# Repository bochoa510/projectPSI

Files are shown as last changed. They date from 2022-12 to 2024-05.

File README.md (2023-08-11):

# projectPSI : Automatic Tire Inflator prototype 

# Index

* CAD
  - housing design using OnShapeCAD
    
*  Code
   - source code used to program microcontroller
 
* Parts
    - detailed list of components used and links 
    
* Previous versions
  - previous versions, keeping for project history
    
* Resources
   - parts resources  
     
* Schematics
   - KiCAD schematic files and board design

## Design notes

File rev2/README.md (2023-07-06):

# to do:

update maincontrol to correctly measure and display PSI

# fix layout design problems:

   I2C pins
   
  pull down resistors for transistors

# goal is to have self contained pcb:

  5v relay moodule w/ isolation
  
  16bit adc module 

# I would like to include surface mount components:

  capacitors
  
  resistors
  
  diodes
  
  atmega328p (maybe)

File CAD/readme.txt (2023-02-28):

Created using OnShape 3D CAD and 3D printed test parts using Makerbot Replicator 5th Gen 

Link to part document
https://cad.onshape.com/documents/6e8889402c3ba4208828449b/w/36755877a1c921f2bab17a01/e/a95ed9e188de5fe185a65eca

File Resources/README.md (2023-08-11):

# Supporting files and resources used to create the PCB and Code 

# Index
* ADS1115
  - adc converter
* 5V Relay Module
  - Relay module with optocoupler isolation

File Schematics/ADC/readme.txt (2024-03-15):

Analog to digital converter schematic and pcb design

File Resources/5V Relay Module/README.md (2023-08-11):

deciding on schematic options

no optocoupler isolation + active high trigger 

(https://components101.com/switches/5v-single-channel-relay-module-pinout-features-applications-working-datasheet)


with optocoupler isolation + active high/low trigger



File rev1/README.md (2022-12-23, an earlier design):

maincontrol.ino contains atmega328p code 

pPSI.zip contains kicad layout files

improvements for rev2

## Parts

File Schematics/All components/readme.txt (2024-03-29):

all parts (excluding 328p section) combined to a single pcb to test complete functionality

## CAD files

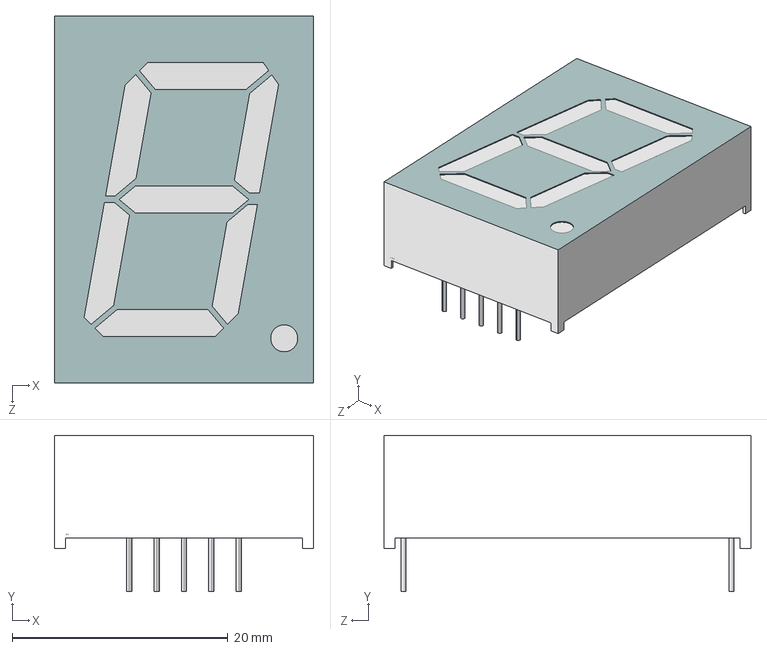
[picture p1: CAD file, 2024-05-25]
CAD/7seg.step
24.0 x 14.5 x 34.0 mm

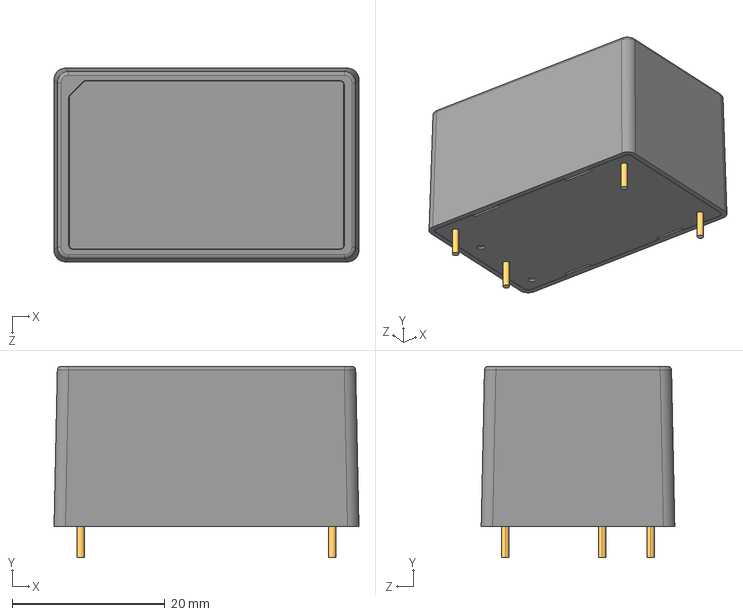
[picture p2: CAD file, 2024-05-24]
Schematics/KiCAD Parts Library/zipfiles/PSK-10D-5/PSK-10D-5.step
40.0 x 25.1 x 25.4 mm

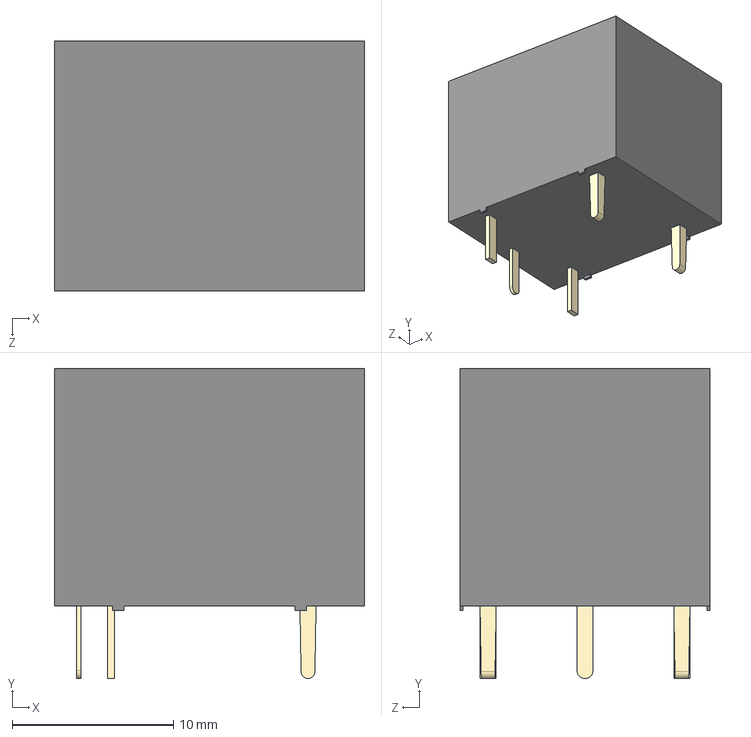
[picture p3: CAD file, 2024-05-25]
CAD/relay.step
19.2 x 19.2 x 15.5 mm

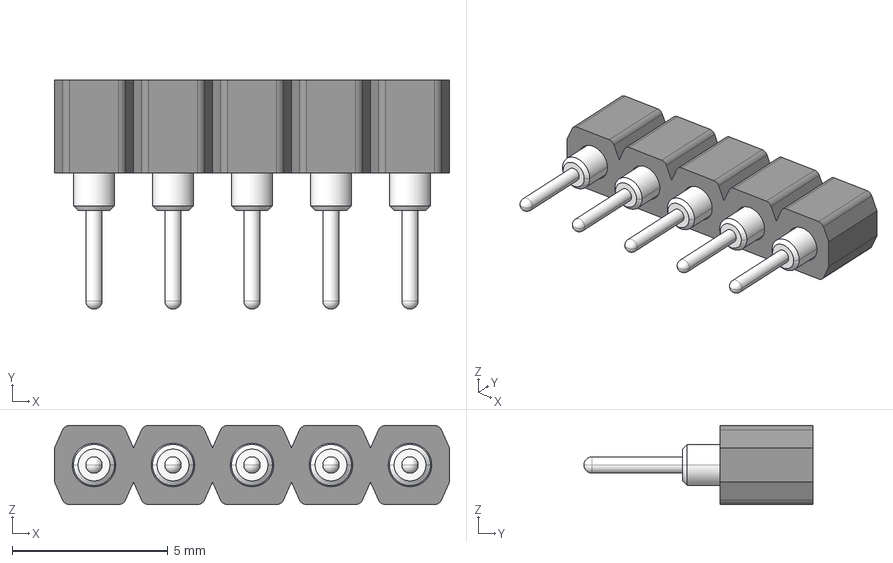
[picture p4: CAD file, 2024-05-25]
CAD/5 pin female header.stp
12.7 x 7.37 x 2.54 mm
D01-997-MOULDING
D01-997-SOCKETBODY x 5
Y3199 x 5

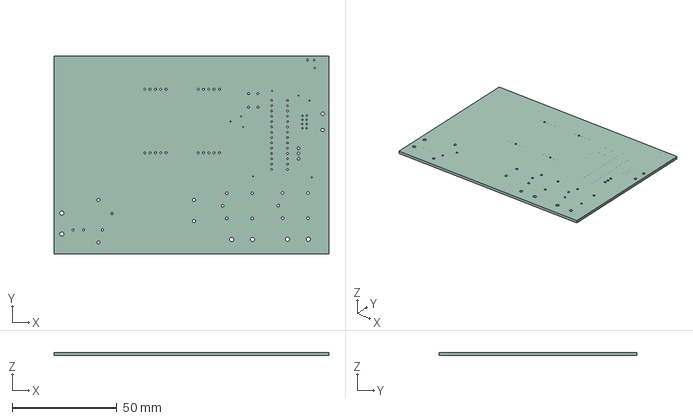
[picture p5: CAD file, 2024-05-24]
CAD/all_components.step
131.5 x 94.8 x 1.60 mm

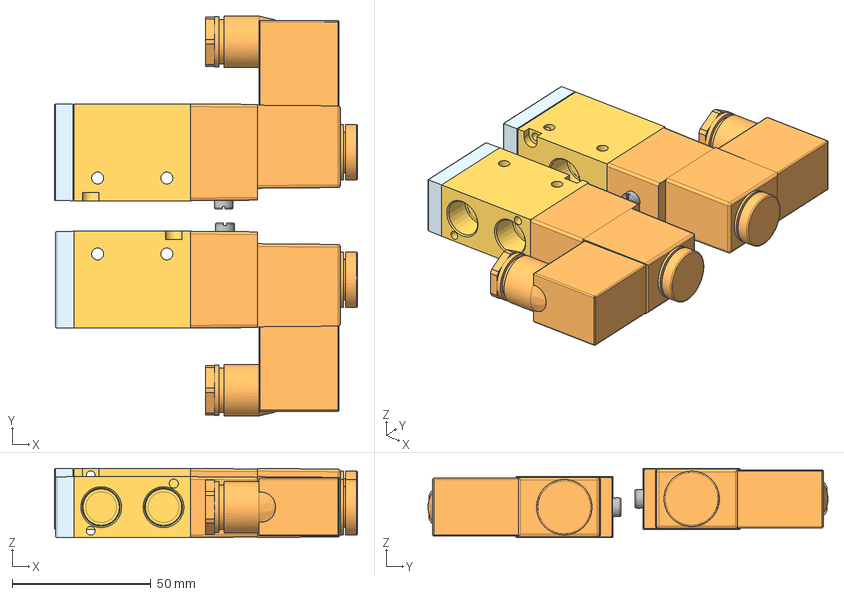
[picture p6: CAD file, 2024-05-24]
CAD/valves.step
109.5 x 144.4 x 25.0 mm
AVS-3212-120A x 8

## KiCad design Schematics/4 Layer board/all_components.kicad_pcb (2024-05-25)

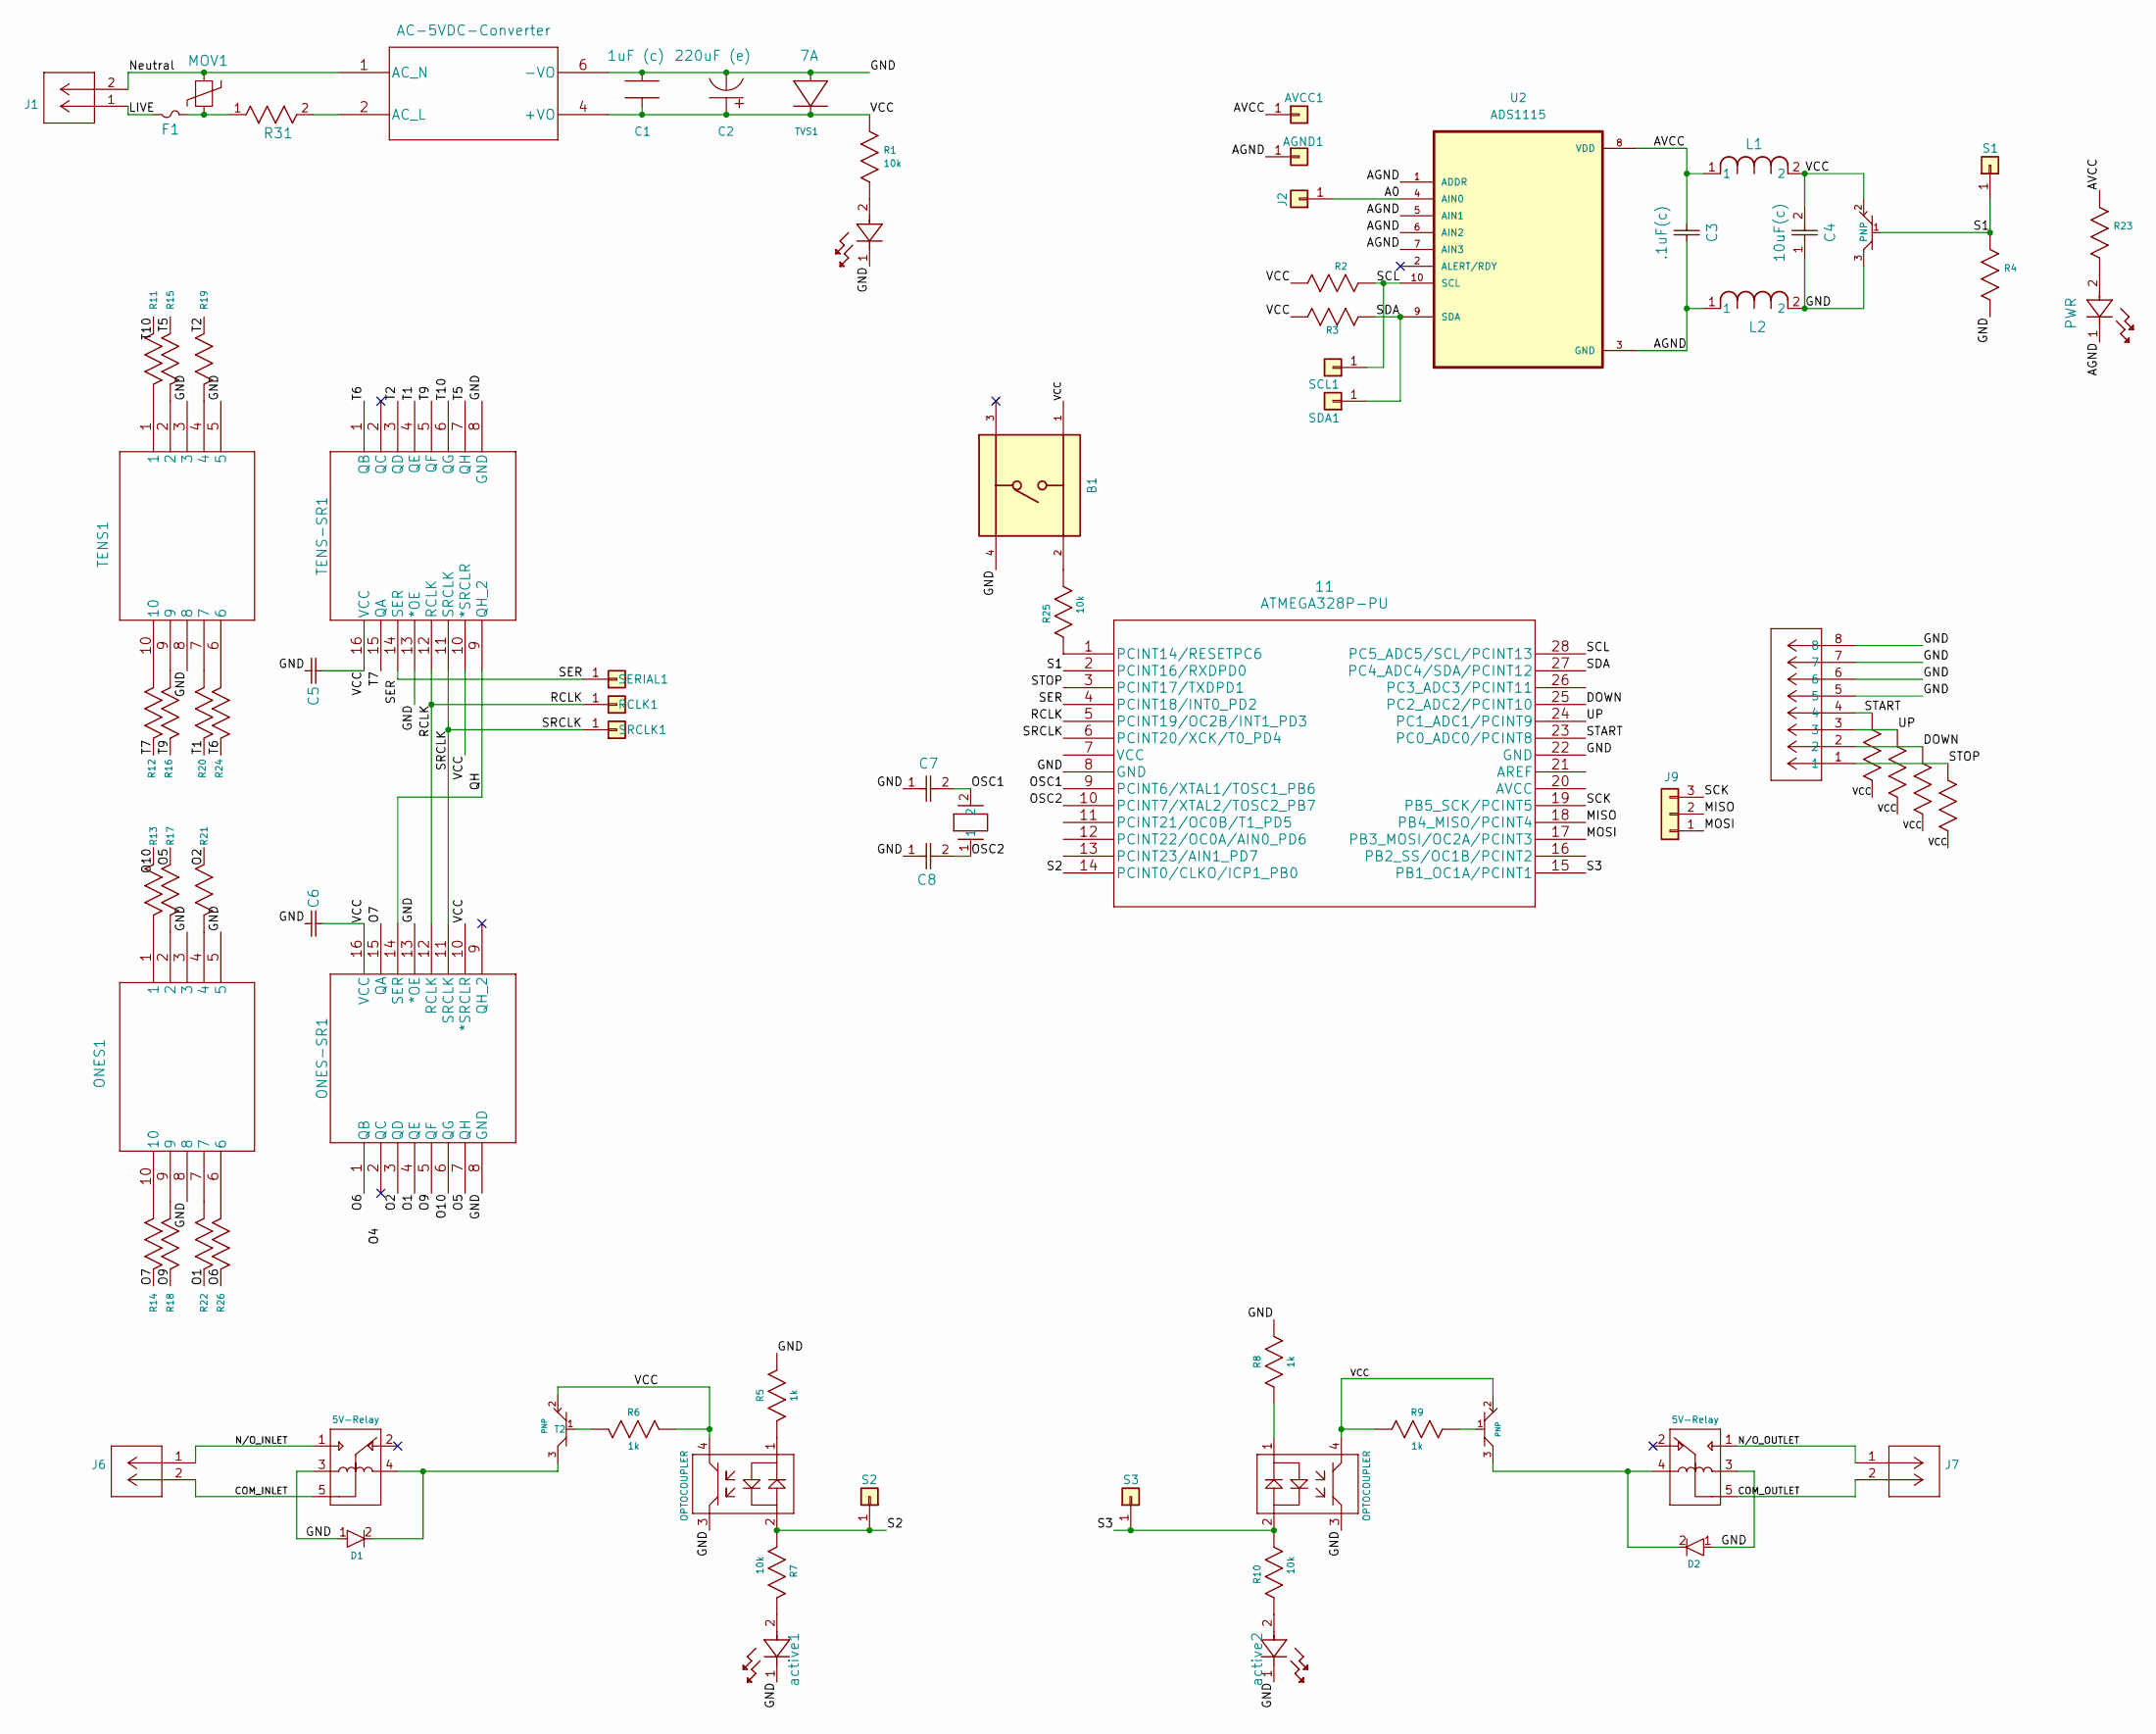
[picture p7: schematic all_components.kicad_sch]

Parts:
11: ATMEGA328P-PU
AGND1: Conn_01x01; 1 pin header
AVCC1: Conn_01x01; 1 pin header
B1: push button
C1: 1uF (c); 1uF(c)
C2: 220uF (e); 220uF Cap (e)
C3, C5, C6: .1uF(c); .1uF Cap (c)
C4: 10uF(c); 10uF Cap (c)
C7, C8: C0805C220J5GAC7210; 22pF Cap (c)
D1, D2: Small-Signal-Diode; small signal diode
F1: FUSE; Fuse
J1, J6, J7: 2 pin header
J2: Conn_01x01; 1 pin header
J3, J4: 5V-Relay; 5V Relay
J8: S08B-PUDSS-1LFSN; 2x4Connector
J9: 3-pin-header; 3 pin header
L1, L2: Ferrite-Bead; ferrite bead
LED1, LED2: PWR; green LED
MOV1: 350V_4.5kA MOV
ONES1: 7-Segment-Display; 7 segment display
ONES-SR1: 8bit-Shift-Register; 8 bit shift register
Q1, Q2: OPTOCOUPLER; optocoupler
R1, R4, R7, R10, R23, R25: 10k; 10kohm
R2, R3: 10kohm
R5, R6, R8, R9, R27, R28, R29, R30: 1k; 1kohm
R11, R12, R13, R14, R15, R16, R17, R18, R19, R20, R21, R22, R24, R26: 100ohm-Resistor; 100ohm
R31: 6.8ohm
RCLK1: Conn_01x01; 1 pin header
S1, S2, S3: Conn_01x01; 1 pin header
SCL1: Conn_01x01; 1 pin header
SDA1: Conn_01x01; 1 pin header
SERIAL1: Conn_01x01; 1 pin header
SRCLK1: Conn_01x01; 1 pin header
T1, T2, T3: PNP; PNP Transistor
TENS1: 7-Segment-Display; 7 segment display
TENS-SR1: 8bit-Shift-Register; 8 bit shift register
TVS1: 7A; 7A TVS diode
U2: ADS1115
XTAL1: HCM4916000000ABJT; Oscillator
active1, active2: red led; red LED
u3: AC-5VDC-Converter; CONV_PSK-10D-5

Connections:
/A0: J2.1, U2.4 (AIN0)
/AGND: AGND1.1, C3.1, L2.1, LED2.1, U2.1 (ADDR), U2.3 (GND), U2.5 (AIN1), U2.6 (AIN2), U2.7 (AIN3)
/AVCC: AVCC1.1, C3.2, L1.1, R23.2, U2.8 (VDD)
/COM_INLET: J3.5, J6.2
/COM_OUTLET: J4.5, J7.2
/DOWN: 11.25 (PC2_ADC2/PCINT10), J8.2, R28.2
/GND: 11.8 (GND), 11.22 (GND), B1.4, C1.2, C2.2, C4.1, C5.2, C6.2, C7.1, C8.1, D1.1, D2.1, J3.3, J4.3, J8.5, J8.6, J8.7, J8.8, L2.2, LED1.1, ONES1.3, ONES1.5, ONES1.8, ONES-SR1.8 (GND), ONES-SR1.13 (*OE), Q1.3, Q2.3, R4.1, R5.1, R8.2, T1.3, TENS1.3, TENS1.5, TENS1.8, TENS-SR1.8 (GND), TENS-SR1.13 (*OE), TVS1.2, active1.1, active2.1, u3.6 (-VO); also elsewhere on the board
/LIVE: F1.2, J1.1
/MISO: 11.18 (PB4_MISO/PCINT4), J9.2
/MOSI: 11.17 (PB3_MOSI/OC2A/PCINT3), J9.1
/Neutral: J1.2, MOV1.1, u3.1 (AC_N)
/N/O_INLET: J3.1, J6.1
/N/O_OUTLET: J4.1, J7.1
/O1: ONES-SR1.4 (QE), R22.2
/O2: ONES-SR1.3 (QD), R21.1
/O5: ONES-SR1.7 (QH), R17.1
/O6: ONES-SR1.1 (QB), R26.2
/O7: ONES-SR1.15 (QA), R14.2
/O9: ONES-SR1.5 (QF), R18.2
/O10: ONES-SR1.6 (QG), R13.1
/OSC1: 11.9 (PCINT6/XTAL1/TOSC1_PB6), C7.2, XTAL1.2
/OSC2: 11.10 (PCINT7/XTAL2/TOSC2_PB7), C8.2, XTAL1.1
/QH: ONES-SR1.14 (SER), TENS-SR1.9 (QH_2)
/RCLK: 11.5 (PCINT19/OC2B/INT1_PD3), ONES-SR1.12 (RCLK), RCLK1.1, TENS-SR1.12 (RCLK)
/S1: 11.2 (PCINT16/RXDPD0), R4.2, S1.1, T1.1
/S2: 11.14 (PCINT0/CLKO/ICP1_PB0), Q1.2, R7.2, S2.1
/S3: 11.15 (PB1_OC1A/PCINT1), Q2.2, R10.2, S3.1
/SCK: 11.19 (PB5_SCK/PCINT5), J9.3
/SCL: 11.28 (PC5_ADC5/SCL/PCINT13), R2.2, SCL1.1, U2.10 (SCL)
/SDA: 11.27 (PC4_ADC4/SDA/PCINT12), R3.2, SDA1.1, U2.9 (SDA)
/SER: 11.4 (PCINT18/INT0_PD2), SERIAL1.1, TENS-SR1.14 (SER)
/SRCLK: 11.6 (PCINT20/XCK/T0_PD4), ONES-SR1.11 (SRCLK), SRCLK1.1, TENS-SR1.11 (SRCLK)
/START: 11.23 (PC0_ADC0/PCINT8), J8.4, R30.2
/STOP: 11.3 (PCINT17/TXDPD1), J8.1, R27.2
/T1: R20.2, TENS-SR1.4 (QE)
/T2: R19.1, TENS-SR1.3 (QD)
/T5: R15.1, TENS-SR1.7 (QH)
/T6: R24.2, TENS-SR1.1 (QB)
/T7: R12.2, TENS-SR1.15 (QA)
/T9: R16.2, TENS-SR1.5 (QF)
/T10: R11.1, TENS-SR1.6 (QG)
/UP: 11.24 (PC1_ADC1/PCINT9), J8.3, R29.2
/VCC: B1.1, C1.1, C2.1, C4.2, C5.1, C6.1, L1.2, ONES-SR1.10 (*SRCLR), ONES-SR1.16 (VCC), Q1.4, Q2.4, R1.2, R2.1, R3.1, R6.1, R9.1, R27.1, R28.1, R29.1, R30.1, T1.2, T2.2, T3.2, TENS-SR1.10 (*SRCLR), TENS-SR1.16 (VCC), TVS1.1, u3.4 (+VO)
unnamed: 11.1 (PCINT14/RESETPC6), R25.1
unnamed: B1.2, R25.2
unnamed: D1.2, J3.4, T2.3
unnamed: D2.2, J4.4, T3.3
unnamed: F1.1, MOV1.2, R31.1
unnamed 48: R19.2, TENS1.4; also elsewhere on the board
unnamed 49: R15.2, TENS1.2; also elsewhere on the board
unnamed 50: R11.2, TENS1.1; also elsewhere on the board
unnamed: LED1.2, R1.1
unnamed: LED2.2, R23.1
unnamed: ONES1.1, R13.2
unnamed: ONES1.2, R17.2
unnamed: ONES1.4, R21.2
unnamed: ONES1.6, R26.1
unnamed: ONES1.7, R22.1
unnamed: ONES1.9, R18.1
unnamed: ONES1.10, R14.1
unnamed: Q1.1, R5.2
unnamed: Q2.1, R8.1
unnamed: R6.2, T2.1
unnamed: R7.1, active1.2
unnamed: R9.2, T3.1
unnamed: R10.1, active2.2
unnamed: R12.1, TENS1.10
unnamed: R16.1, TENS1.9
unnamed: R20.1, TENS1.7
unnamed: R24.1, TENS1.6
unnamed: R31.2, u3.2 (AC_L)

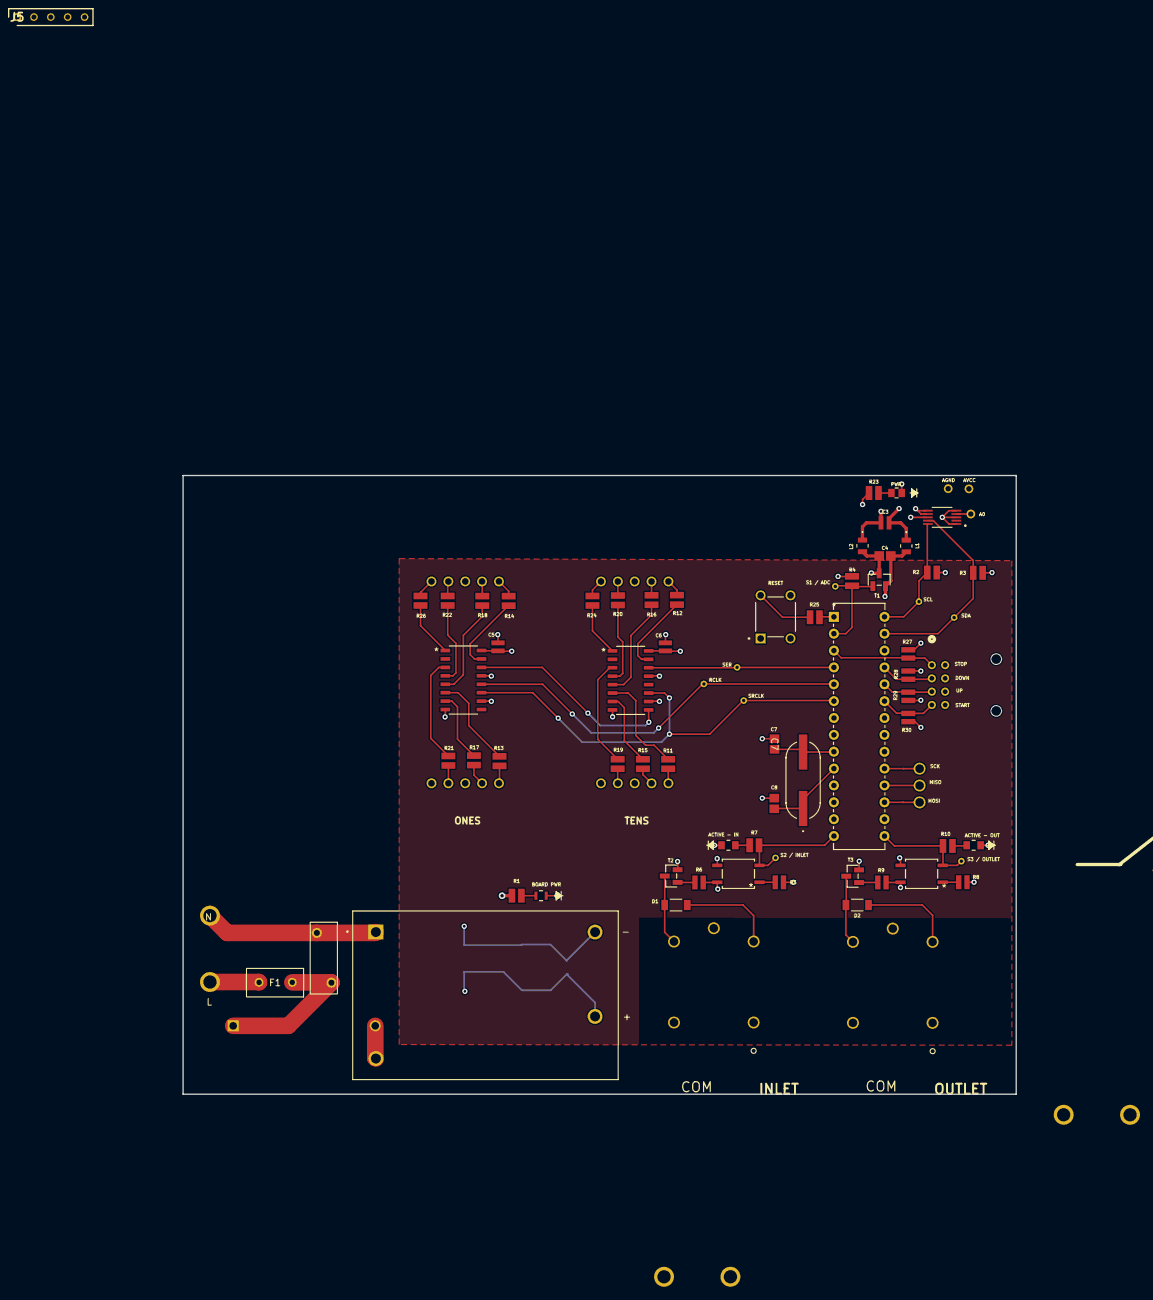
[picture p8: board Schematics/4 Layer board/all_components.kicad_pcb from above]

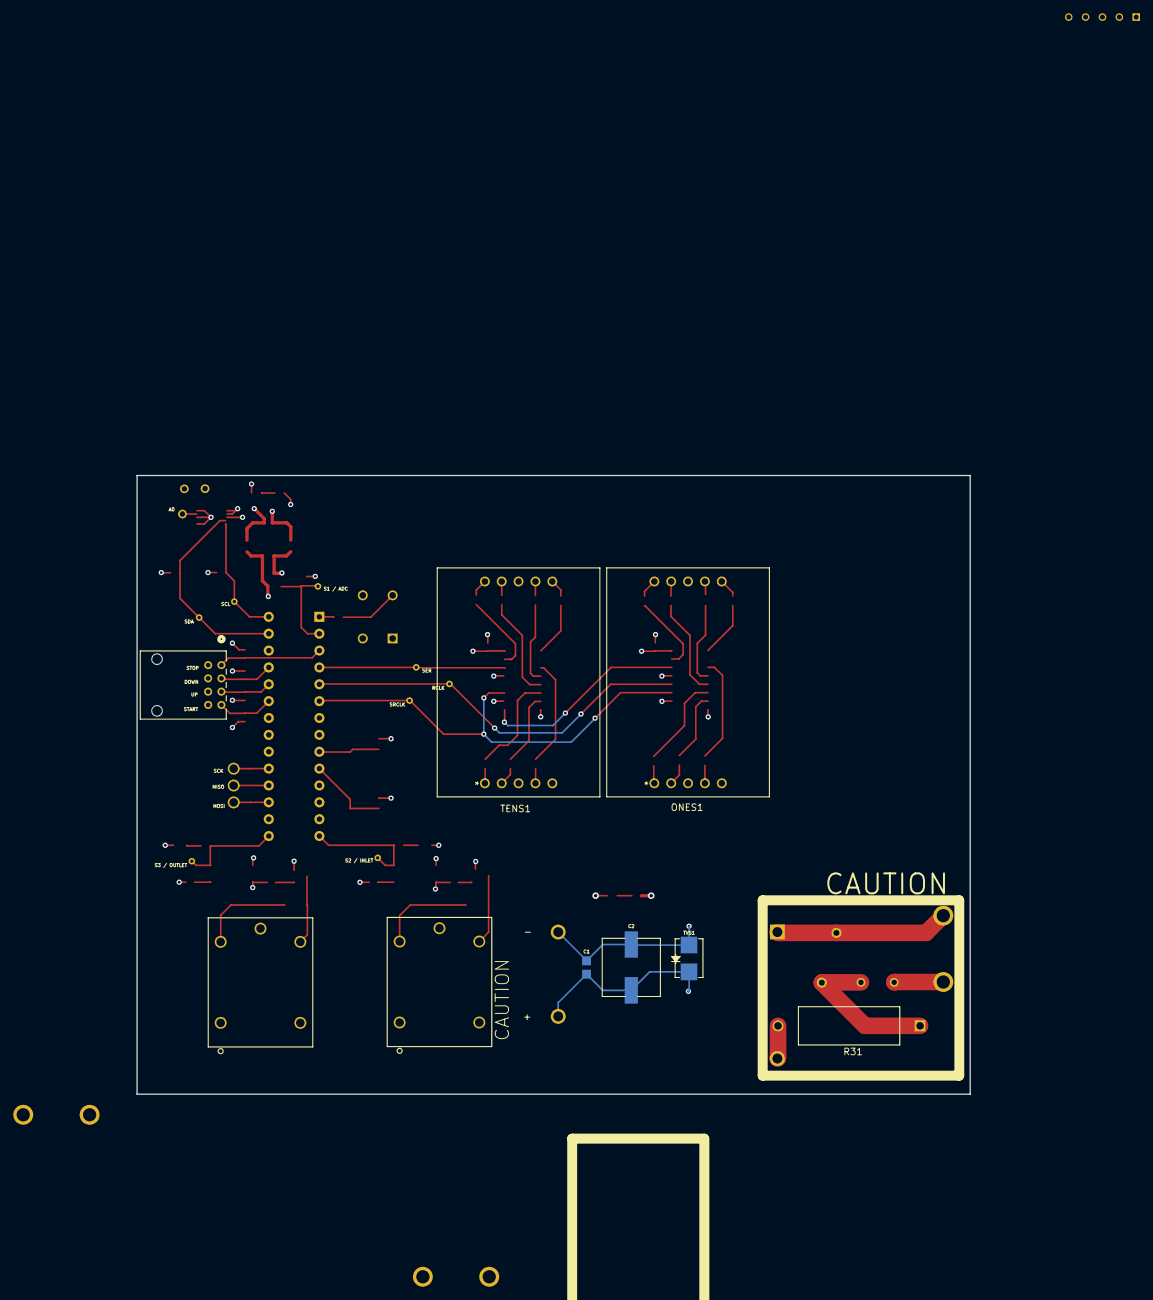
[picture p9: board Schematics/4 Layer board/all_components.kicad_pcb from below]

Board: 4 copper layers, 125.5 x 93.2 mm, 83 parts (9 on the bottom side), 71 nets.

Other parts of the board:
J5: D01-9970542; 1x5 female header

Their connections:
/GND: J5.1, J5.3; also elsewhere on the board
unnamed 48: J5.2; also elsewhere on the board
unnamed 49: J5.4; also elsewhere on the board
unnamed 50: J5.5; also elsewhere on the board

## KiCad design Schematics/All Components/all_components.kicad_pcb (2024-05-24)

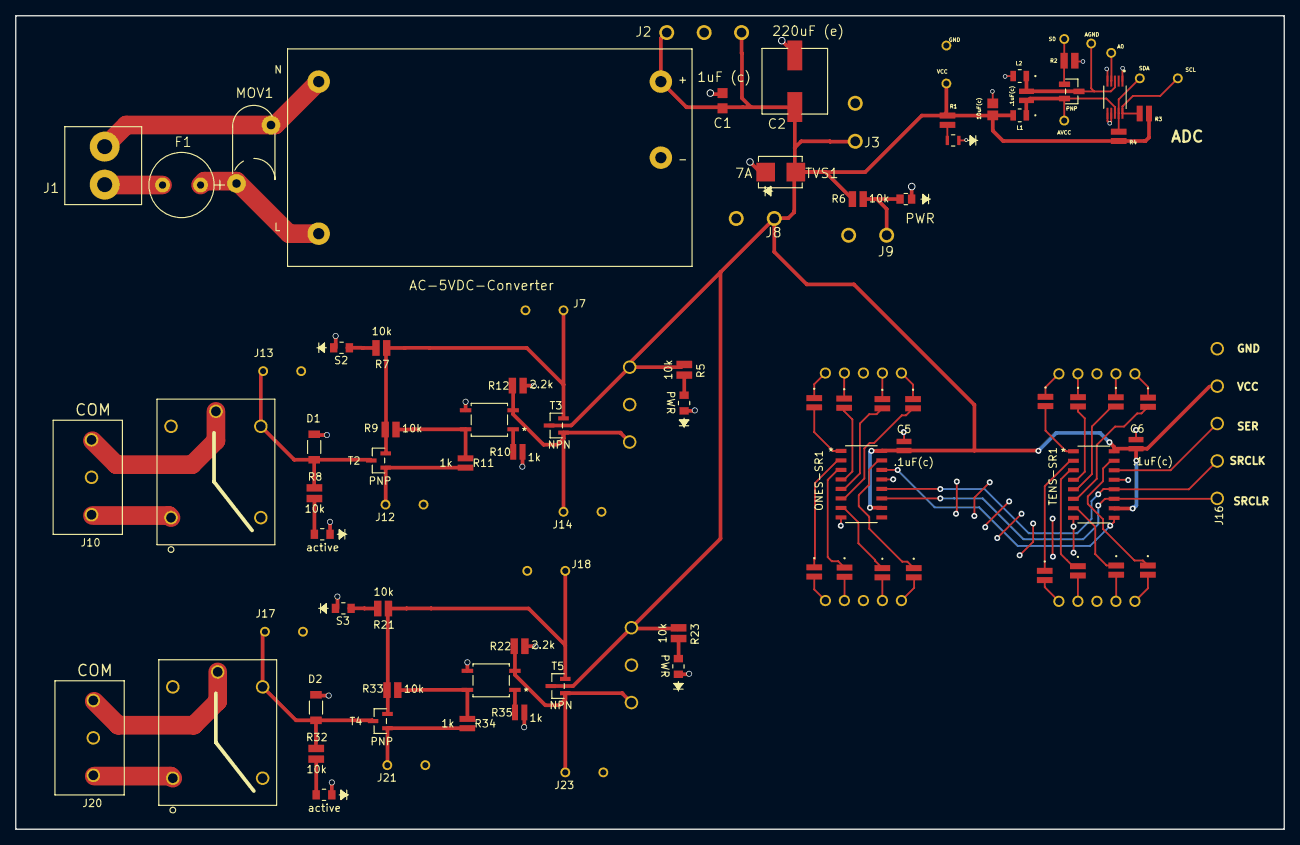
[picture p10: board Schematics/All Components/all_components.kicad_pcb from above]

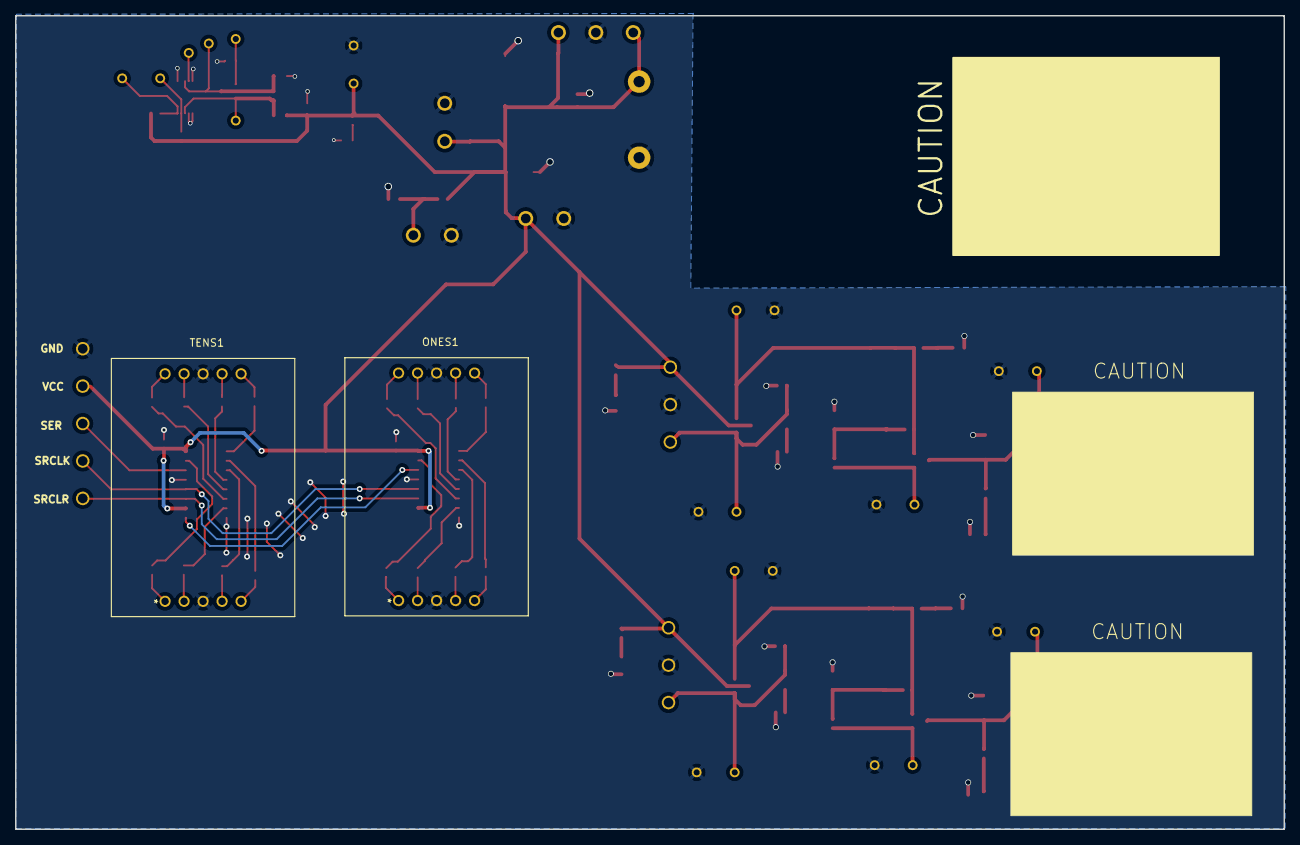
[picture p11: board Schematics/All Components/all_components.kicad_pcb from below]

Board: 4 copper layers, 169.5 x 108.7 mm, 95 parts (2 on the bottom side), 62 nets.

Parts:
AGND: Conn_01x01; 1 pin header
AVCC: Conn_01x01; 1 pin header
C1: 1uF (c); 1uF ceramic capacitor
C2: 220uF (e); 220uF electrolytic capacitor
C3, C5, C6: .1uF(c); .1uF ceramic capacitor
C4: 10uF(c); 10uF Ceramic Capacitor
D1, D2: Small-Signal-Diode; small signal diode
F1: FUSE
J1: 2-pin-terminal-block
J2: Conn_01x03; 3 pin header
J3, J7, J8, J9, J12, J13, J14, J17, J18, J21, J23: Conn_01x02; 2 pin header
J4, J5: 2-pin-header; 2 pin header
J6: Conn_01x01; 1 pin header
J10, J20: 3-pin-terminal-block
J11, J22: 5V-Relay; 5V Relay
J15: S1; 3 pin header
J16: 5-pin-header; 5 pin header
J19: S2; 3 pin header
L1, L2: Ferrite-Bead; ferrite bead
LED1, LED2: PWR; green LED
MOV1: 470V-Varistor; 470V Varistor
ONES1: 7-Segment-Display; 7 segment display
ONES-SR1: 8bit-Shift-Register; 8 bit shift register
PWR: green led; green LED
PWR#2: green led; green LED
Q1, Q2: OPTOCOUPLER; optocoupler
R1, R2, R5, R6, R7, R8, R9, R21, R23, R32, R33: 10k; 10kohm resistor
R3, R4: 10kohm; 10kohm resistor
R10, R11, R34, R35: 1k; 1kohm resistor
R12, R22: 2.2k; 2.2kohm resisitor
R13, R14, R15, R16, R17, R18, R19, R20, R24, R25, R26, R27, R28, R29, R30, R31: 100ohm-Resistor; 100ohm resistor
S0: Conn_01x01; 1 pin header
S2, S3: green led; green LED
T1, T2, T4: PNP; PNP Transistor
T3, T5: NPN; NPN Transistor
TENS1: 7-Segment-Display; 7 segment display
TENS-SR1: 8bit-Shift-Register; 8 bit shift register
TVS1: 7A; 7A TVS diode
U1: ADS1115IDGST; ADS1115
active: red led; red LED
active#2: red led; red LED
u1: AC-5VDC-Converter; ac-dc converter

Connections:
/A0: J6.1, U1.4 (AIN0)
/AGND: AGND.1, C3.1, L2.1, T1.3, U1.3 (GND)
/AVCC: AVCC.1, C3.2, L1.1, T1.2, U1.8 (VDD)
/COM_INLET: J10.1, J11.5, J20.1, J22.5
/GND: C1.1, C2.2, C4.1, C5.2, C6.2, D1.1, D2.1, J2.2, J3.2, J4.2, J7.2, J8.2, J9.2, J10.2, J11.3, J12.2, J13.2, J14.2, J15.2, J16.5, J17.2, J18.2, J19.2, J20.2, J21.2, J22.3, J23.2, L2.2, LED1.1, LED2.1, ONES1.3, ONES1.8, ONES-SR1.8 (GND), ONES-SR1.13 (*OE), PWR.1, PWR#2.1, Q1.3, Q2.1, Q2.3, R2.1, R10.2, R12.1, R22.1, R35.1, R35.2, S2.1, S3.1, TENS1.3, TENS1.8, TENS-SR1.8 (GND), TENS-SR1.13 (*OE), TVS1.2, U1.1 (ADDR), U1.5 (AIN1), U1.6 (AIN2), U1.7 (AIN3), active.1, active#2.1, u1.3 (-VO)
/INLET_VCC: J7.1, R7.2, R9.2, T2.2, T3.2
/LIVE: F1.2, J1.1
/Neutral: J1.2, MOV1.1, u1.1 (AC_N)
/N/O_INLET: J10.3, J11.1, J20.3, J22.1
/O1: ONES-SR1.4 (QE), R16.2
/O2: ONES-SR1.3 (QD), R26.1
/O4: ONES-SR1.2 (QC), R24.1
/O5: ONES-SR1.7 (QH), R27.1
/O6: ONES-SR1.1 (QB), R13.2
/O7: ONES-SR1.15 (QA), R25.1
/O9: ONES-SR1.5 (QF), R15.2
/O10: ONES-SR1.6 (QG), R14.2
/OUTLET_VCC: J18.1, R21.1, R21.2, R33.2, S3.2, T4.2, T5.2
/QH: ONES-SR1.14 (SER), TENS-SR1.9 (QH_2)
/RCLK: J16.2, ONES-SR1.12 (RCLK), TENS-SR1.12 (RCLK)
/S0: R2.2, S0.1, T1.1
/S1: J14.1, J15.3, Q1.2, R12.2, T3.1
/S2: J19.3, J23.1, Q2.2, R22.2, T5.1
/SCL: J5.2, R3.2, U1.10 (SCL)
/SDA: J5.1, R4.2, U1.9 (SDA)
/SER: J16.3, TENS-SR1.14 (SER)
/SRCLK: J16.1, ONES-SR1.11 (SRCLK), TENS-SR1.11 (SRCLK)
/T1: R17.2, TENS-SR1.4 (QE)
/T2: R31.1, TENS-SR1.3 (QD)
/T4: R29.1, TENS-SR1.2 (QC)
/T5: R30.1, TENS-SR1.7 (QH)
/T6: R19.2, TENS-SR1.1 (QB)
/T7: R28.1, TENS-SR1.15 (QA)
/T9: R18.2, TENS-SR1.5 (QF)
/T10: R20.2, TENS-SR1.6 (QG)
/VCC: C1.2, C2.1, C4.2, C5.1, C6.1, J2.1, J2.3, J3.1, J4.1, J8.1, J15.1, J16.4, J19.1, L1.2, ONES-SR1.10 (*SRCLR), ONES-SR1.16 (VCC), PWR.2, PWR#2.2, R1.2, R3.1, R4.1, R5.1, R5.2, R6.2, R23.1, R23.2, T3.3, T5.3, TENS-SR1.10 (*SRCLR), TENS-SR1.16 (VCC), TVS1.1, u1.4 (+VO)
J12: J12.1, Q1.4, R9.1, R11.1, R11.2, T2.1
J17: D2.2, J17.1, J22.4, R32.1, T4.3
J21: J21.1, Q2.4, R33.1, R34.1, R34.2, T4.1
unnamed: J9.1, LED2.2, R6.1
unnamed: D1.2, J11.4, J13.1, R8.1, R8.2, T2.3, active#2.2
unnamed: LED1.2, R1.1
unnamed: ONES1.1, R25.2
unnamed: ONES1.2, R27.2
unnamed: ONES1.4, R26.2
unnamed: ONES1.5, R24.2
unnamed: ONES1.6, R13.1
unnamed: ONES1.7, R16.1
unnamed: ONES1.9, R15.1
unnamed: ONES1.10, R14.1
unnamed: Q1.1, R10.1
unnamed: R7.1, S2.2
unnamed: R28.2, TENS1.1
unnamed: R30.2, TENS1.2
unnamed: R31.2, TENS1.4
unnamed: R29.2, TENS1.5
unnamed: R20.1, TENS1.10
unnamed: R18.1, TENS1.9
unnamed: R17.1, TENS1.7
unnamed: R19.1, TENS1.6
unnamed: F1.1, MOV1.2, u1.2 (AC_L)
OUT_PWR: R32.2, active.2

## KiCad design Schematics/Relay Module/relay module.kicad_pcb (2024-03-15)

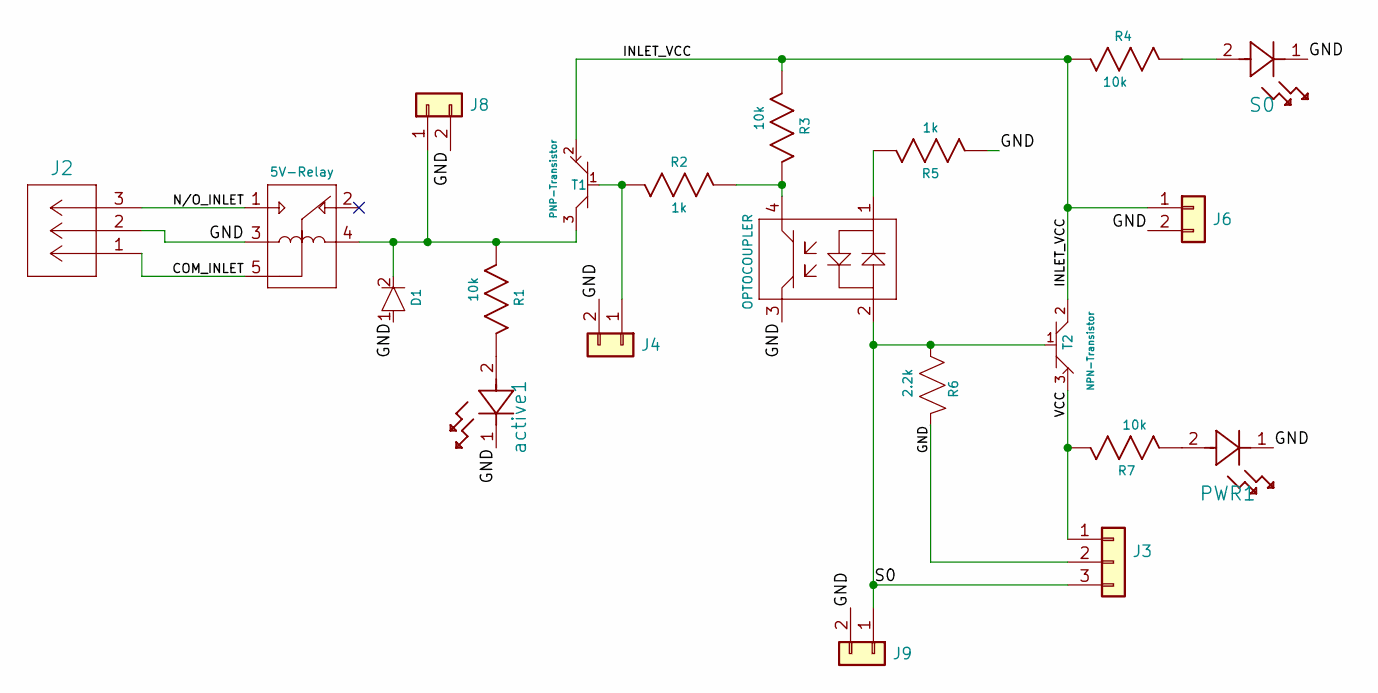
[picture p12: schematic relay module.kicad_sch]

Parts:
D1: Small-Signal-Diode; small signal diode
J1: 5V-Relay; 5V Relay
J2: 3-pin-terminal-block
J3: Conn_01x03; 3 pin header
J4, J6, J8, J9: Conn_01x02; 2 pin header
PWR1: green led; green LED
Q1: OPTOCOUPLER; optocoupler
R1, R3, R4, R7: 10k; 10kohm resistor
R2, R5: 1k; 1kohm resistor
R6: 2.2k; 2.2kohm resisitor
S0: green led; green LED
T1: PNP-Transistor; PNP Transistor
T2: NPN-Transistor; NPN Transistor
active1: red led; red LED

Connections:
/COM_INLET: J1.5, J2.1
/GND: D1.1, J1.3, J2.2, J3.2, J4.2, J6.2, J8.2, J9.2, Q1.3, R5.2, R6.1, S0.1; also elsewhere on the board
/INLET_VCC: J6.1, R3.2, R4.2, T1.2, T2.2
/N/O_INLET: J1.1, J2.3
/S0: J3.3, J9.1, Q1.2, R6.2, T2.1
/VCC: J3.1, R7.1, T2.3
unnamed: J4.1, R2.2, T1.1
unnamed: D1.2, J1.4, J8.1, R1.2, T1.3
unnamed 8: R7.2; also elsewhere on the board
unnamed: Q1.1, R5.1
unnamed: Q1.4, R2.1, R3.1
unnamed 11: R1.1; also elsewhere on the board
unnamed: R4.1, S0.2

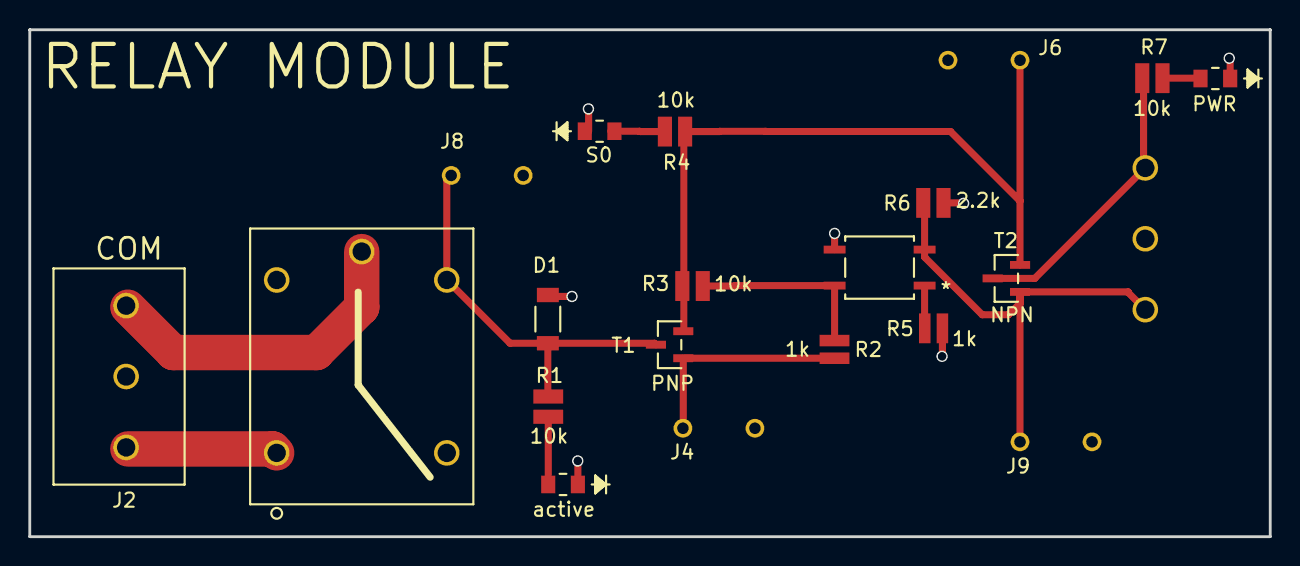
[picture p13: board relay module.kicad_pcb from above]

Board: 2 copper layers, 87.5 x 35.8 mm, 21 parts (0 on the bottom side), 13 nets.

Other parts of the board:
PWR: green led; green LED
active: red led; red LED

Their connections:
/GND: PWR.1, active.1; also elsewhere on the board
unnamed 8: PWR.2; also elsewhere on the board
unnamed 11: active.2; also elsewhere on the board

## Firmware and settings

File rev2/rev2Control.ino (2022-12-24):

#include "ADS1X15.h"

ADS1115 ADS(0x48);

const byte digit_pattern[10] =
{
  // 74HC595 Outpin Connection with 7segment display.
  // Q0 Q1 Q2 Q3 Q4 Q5 Q6 Q7
  // a  b  c  d  e  f  g  DP
  0b11111100,  // 0
  0b01100000,  // 1
  0b11011010,  // 2
  0b11110010,  // 3
  0b01100110,  // 4
  0b10110110,  // 5
  0b10111110,  // 6
  0b11100000,  // 7
  0b11111110,  // 8
  0b11110110,  // 9
  
};
/*
 * RESET 
 * SCL A5 | 28
 * SDA A4 | 27
 * SER A2
 * LATCH A3
 * CLK A1 | 23
 * INLET 0 | 2
 * STOP 2 | 4
 * OUTLET 1
 * UP 6
 * DOWN 7
 * START 8
 * ADC 9
 */

int latchPin = A3;                                  //Pin connected to ST_CP of 74HC595 pin 12
int clkPin = A1;                                   //Pin connected to SH_CP of 74HC595 pin 11
int dtPin = A2;                                    //Pin connected to DS of 74HC595 pin 14

int startButton = 8;                               //start
int downButton = 7;                                //subtract
int upButton = 6;                                  //add 
int stopButton = 2;                                //stop

int tensPSI = 3;                                             //variables to update display
int onesPSI = 5;
int targetPSI = 35;                                          //variable to store what the PSI is being set to

volatile bool pressed = false;

int sensor = 9;                                    //sensor 
int valve_in = 0;
int valve_out = 1;

int sensorValue;                                           //variable to store raw sensor data

void setup() {
  pinMode(valve_in,OUTPUT);  
  pinMode(valve_out,OUTPUT);
  pinMode(sensor, OUTPUT);        
  
  digitalWrite(valve_in,LOW);
  digitalWrite(valve_out,LOW);
  digitalWrite(sensor,LOW);
  
   
  pinMode(latchPin, OUTPUT);    //ST_CP of 74HC595
  pinMode(clkPin, OUTPUT);      //SH_CP of 74HC595
  pinMode(dtPin, OUTPUT);       //DS of 74HC595
    
  pinMode(upButton,INPUT);
  pinMode(downButton,INPUT);
  pinMode(startButton,INPUT);
  pinMode(stopButton,INPUT);

  digitalWrite(latchPin, LOW);
  shiftOut(dtPin, clkPin, LSBFIRST, digit_pattern[5]);   
  shiftOut(dtPin, clkPin, LSBFIRST, digit_pattern[3]);
  digitalWrite(latchPin, HIGH);  
  attachInterrupt(digitalPinToInterrupt(stopButton),Stop,FALLING);

}

int readSensor(){                                                // function that returns PSI 
    digitalWrite(sensor,HIGH);
    delay(2000);
    Serial.begin(115200);                                                 //initialize serial communication at 115200 bits per second:      
    delay(2000);
    
    ADS.begin();
    ADS.setGain(1);      // max 4.096V , [(4.096 * 37.5) - 18.75] = 135 -> CANNOT EXCEED 130 PSI 
    ADS.setDataRate(5);  // fastest for 1115

    //should take average of reading 

    for(int i=1; i == 10; i++){ 
      int16_t val += ADS.readADC(0); 
      float V = ADS.toVoltage(1);  // voltage factor
      float Voltage = (val * V);
      int psi = (Voltage * 37.5) - 18.75;
      float fpsi = (Voltage * 37.5) - 18.75;
    }
    float avgVal = val / 10
    float avgV = V / 10 
     

    //do stuff 
    
    digitalWrite(sensor,LOW); //turn off sensor 
    return psi
 //   sensorValue = analogRead(sensor);                            // read the input on analog pin 0:
//    float voltage = sensorValue * (aref_voltage / 1023.0);       // Convert the analog reading (which goes from 0 - 1023) to a voltage (0 - 5V):
  //  int rounding = (voltage * 100) + .5;                         // to round from x.xxxxxx precision to .1, store in INT variable: (x.xxxx * 100) + .05),  
   // float v = (rounding) / 100.0;                                // which will move decimal over to xx (+.5 insures INT rounds up), then in another float variable, (xx / 100.0 ) to move decimal back over : x.x
           
    
 //   float pa =   ( (v - 0.50) / (3.3335) )  * 1000000 ;
 //   float converting = pa * (.000145161);
 //   psi = converting + .5 ;
      
}

void startInflation(){
 
  bool stopState = digitalRead(stopButton);
  while (stopState != pressed){                         // check stop state at multiple stages to ensure immediate stopping 
      stopState = digitalRead(stopButton);              
      digitalWrite(valve_in,LOW);                       //sequence opens from tank,  
      digitalWrite(valve_out,HIGH);                     //and closes exhaust
      stopState= digitalRead(stopButton);
      if (stopState == pressed){
        digitalWrite(valve_in,HIGH);                  // sequence closes tank 
        digitalWrite(valve_out,HIGH);                 // and exhaust
        break;                                        //back to main function                              
      }
      delay(100);
     }
}

void startDeflation(){
  bool stopState = digitalRead(stopButton);
  while (stopState != pressed){
      digitalWrite(valve_in,HIGH);
      digitalWrite(valve_out,LOW);
      stopState= digitalRead(stopButton);
      if (stopState == pressed){
        digitalWrite(valve_in,HIGH);
        digitalWrite(valve_out,HIGH);
        break;
      }
      delay(100);
     } 
}
//

void Stop(){
  digitalWrite(valve_in,LOW);                       //closes from tank,  
  digitalWrite(valve_out,LOW);                     //and closes exhaust
  
  digitalWrite(latchPin, LOW);
  shiftOut(dtPin, clkPin, LSBFIRST, digit_pattern[onesPSI]);   
  shiftOut(dtPin, clkPin, LSBFIRST, digit_pattern[tensPSI]);
  digitalWrite(latchPin, HIGH);
 }

void loop() {
  bool upState = digitalRead(upButton);                               //check status of buttons
  bool downState = digitalRead(downButton);
  bool startState = digitalRead(startButton);
//
  if(upState == pressed){                                    //add to target pressure
    if (onesPSI != 9 or tensPSI !=9){                       //highest possible diplay 99 -> if 99, do nothing
      targetPSI += 1;                                       //update target PSI
      tensPSI = targetPSI / 10 ;                            //extract tens value to push onto shift register
      onesPSI = targetPSI - (tensPSI * 10) ;                //extract ones value to push onto shift register
//    
      digitalWrite(latchPin,LOW);                      //low pin allows writing to shift register
      shiftOut(dtPin, clkPin, LSBFIRST, digit_pattern[onesPSI]);   
      shiftOut(dtPin, clkPin, LSBFIRST, digit_pattern[tensPSI]);
      digitalWrite(latchPin,HIGH);                     //high pin closes writing to shift register
      delay(180);                                           //180ms delay
    }
  }
  else if (downState == pressed){                            //subtract from target pressure     
    if (onesPSI != 0 or tensPSI !=0){                       //lowest possible display 00 -> if 00, do nothing
      targetPSI -= 1;                                       //update target PSI
      tensPSI = targetPSI / 10 ;                            //extract tens value to push onto shift register
      onesPSI = targetPSI - (tensPSI * 10) ;                //extract ones value to push onto shift register
      
      digitalWrite(latchPin,LOW);                      //active low pin allows writing to shift register
      shiftOut(dtPin, clkPin, LSBFIRST, digit_pattern[onesPSI]);   
      shiftOut(dtPin, clkPin, LSBFIRST, digit_pattern[tensPSI]);
      digitalWrite(latchPin,HIGH);                     //active high pin closes writing to shift register
      delay(180);                                           //180ms delay 
    }
  }
  else if (startState == pressed){
    int pressure = readSensor();                            //READ SENSOR
    do {                             //IF SENSOR DATA BELOW TARGET -> START INFLATION      
      digitalWrite(valve_in,HIGH);                       //sequence opens from tank,  
      digitalWrite(valve_out,LOW);                     //and closes exhaust
      delay(2000);
      digitalWrite(valve_in,LOW);                       //closes from tank,  
      digitalWrite(valve_out,LOW);                     //and closes exhaust
  
      pressure = 60;
    } while (pressure < targetPSI);
      tensPSI = (pressure / 10);                            //extract tens value to push onto shift register
      onesPSI = pressure - (tensPSI * 10);                //extract ones value to push onto shift register
      digitalWrite(latchPin,LOW);                      //active low pin allows writing to shift register
      shiftOut(dtPin, clkPin, LSBFIRST, digit_pattern[onesPSI]);   
      shiftOut(dtPin, clkPin, LSBFIRST, digit_pattern[tensPSI]);
      digitalWrite(latchPin,HIGH);                     //active high pin closes writing to shift register
      delay(180);
  }         
}

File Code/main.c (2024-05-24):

#include <avr/io.h>
#include <util/delay.h>
#include <stdint.h>
#include <stdbool.h>
/*
const uint8_t digit_pattern[10] = {
	0xDD, //0b11011101, //0
	0x50, //0b01010000, //1
	0xCB, //0b11001011, //2
	0x5B, //0b01011011, //3
	0x56, //0b01010110, //4
	0x1F, //0b00011111, //5
	0x9F, //0b10011111, //6
	0x58, //0b01011000, //7
	0xDF, //0b11011111, //8
	0x5E, //0b01011110, //9
}
/

void setDigits(){

	while (1){
	
		PORTD |= (1 << PORTD7);
		PORTD |= (1 << PORTD6);
		PORTD |= (1 << PORTD5);

		_delay_ms(1000);
		PORTD &= ~(1 << PORTD7);
		PORTD &= ~(1 << PORTD6);
		PORTD &= ~(1 << PORTD5);
		_delay_ms(500);
		}
}

int main(void){
	//set pins for serial , clock and latch as outputs
	//DDRD = 11100000
	DDRD |= (1 << DDD7);
	DDRD |= (1 << DDD6);
	DDRD |= (1 << DDD5);
	unsigned char zero = 0b11011101;	
	while(1){
		for (int i = 0; i < 8; i++){
			unsigned char bit = (zero >> i) & 1;
			(bit) ? (PORTD |= (1 << PORTD7)) : (PORTD &= ~(1 << PORTD7));
			_delay_ms(1000);
		}
		
		PORTD &= ~(1 << PORTD7);
		_delay_ms(5000);
	}
	
	return 0;
}
*/

#define LATCH_PIN 8
#define CLOCK_PIN 12
#define DATA_PIN 2
#define LSBFIRST 0
#define MSBFIRST 1
#define HIGH 1
#define LOW 0
/*
void digitalWrite(uint8_t pin, uint8_t value) {
    if (value == HIGH) {
        PORTD |= (1 << pin); // Set pin HIGH
    } else 
    	    PORTD &= ~(1 << pin); // Set pin LOW
    }

void shiftOut(uint8_t dataPin, uint8_t clockPin, uint8_t bitOrder, uint8_t val) {
    uint8_t i;

    digitalWrite(clockPin, LOW);
    for (i = 0; i < 8; i++) {
        if (bitOrder == LSBFIRST) {
           *PORTD |= (1 << dataPin); // Set data pin high or low based on LSB
            PORTD &= ~(1 << clockPin); // Clock pin low
            
		digitalWrite(dataPin, val & 1);
	    	val >>= 1; // Shift bits to the right
			   //
        } else {
		
            PORTD |= (1 << dataPin); // Set data pin high or low based on MSB
            PORTD &= ~(1 << clockPin); // Clock pin low
            
		digitalWrite(dataPin,(val & 128) !=0);
	    	val <<= 1; // Shift bits to the left
        }

 	digitalWrite(clockPin, HIGH);
	digitalWrite(clockPin, LOW);
    }
}
*/
void setup(){
	    // Set pins to output
    DDRB &= (0);
    DDRD &= (0);

    DDRB |= (1 << DDB0); // Latch pin
    DDRB |= (1 << DDB4); // Clock pin
    DDRD |= (1 << DDD2); // Data pin
    
}
int main (void){
    	setup();
        while(1){
	// Ground latchPin and hold low for as long as you are transmitting
		PORTB &= ~(1 << LATCH_PIN);
        // Shift out the desired value (LSB first)
        //shiftOut(DATA_PIN, CLOCK_PIN, LSBFIRST, 221);
	       	uint8_t num = 1;
		uint8_t val = num;	
			
		for (uint8_t i = 0; i < 8; i++){
			if ( (val&1) == HIGH) {
				PORTD |= (1 << DATA_PIN);
			
			}else {
				PORTD &= ~(1 << DATA_PIN);			
			}
			val >>=1;

			PORTB |= (1 << CLOCK_PIN);
			PORTB &= ~(1 << CLOCK_PIN);
		}
	// Return the latch pin high to signal chip that it no longer needs to listen for information
       		PORTB |= (1 << LATCH_PIN);
		_delay_ms(1000);
	}
	return 0;
}

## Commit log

2023-08-10 Module Schematic.md
2024-03-15 Create ADC
2024-05-02 updated files
    [ADC.kicad_pcb, ADC.kicad_sch, Atmega328p.kicad_pcb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]
2024-05-24 updated board and kicad lib
    [PSK-10D-5.step, ac-dc module.step, all_components.kicad_pcb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]
2024-05-25 updated kicad board and parts library
    [5 pin female header.stp, 7seg.step, all_components.kicad_pcb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]
